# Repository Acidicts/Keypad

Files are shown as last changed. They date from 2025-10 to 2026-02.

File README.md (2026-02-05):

# A Numpad or Keypad
## Do as you please with it

It has:
- 16 standard 1:1 aspect ratio keys
- A 1:2 aspect ratio key
- Rotary Encoder
- Seeed Studio Xiao RP2040

The order of assembly/soldering is:
- The Diodes
- The Seeed Studio Xiao RP2040
- The Rotary Encoder
- Keys
- Keycaps Encoder Knob

This is yet to have firmware made for it as it is easier to debug with the actual hardware on hand.
Will be using either **KMK** or **QMK** most likely (kmk due to being easier to learn) and will be referencing [this](https://github.com/Acidicts/Hackpad)

The Rotary Encoder can be used as an audio knob all the way to being a selector for presets for different key setups.

Here is a render of the finished product:
keypad_render

Case:


<div>
  
  
</div>

https://github.com/user-attachments/assets/b589e256-21bc-4e0a-8186-24f3bf2696fe



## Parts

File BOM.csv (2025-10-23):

Item | Store | Quantity | Price(£) | Price ($) | Shipping | Total
Seeed Studio Xiao RP2040 | Seeed Studio | 1 | N/A | $3.90 | $3.68 | $7.58
Key Switches (10 pack) | Amazon | 2 | £3.49 | $9.28 | Prime | $9.28
PCB | JLCPCB | 5 | N/A | $2.00 | $2.20 | $4.20
Diodes ( Multiples of 50 ) | LCSC | 1 | N/A | $0.52 | $4.35 | $4.89
EC11 Rotary Encoder | LCSC | 1 | N/A | $1.81 | $4.35 | $7.57
 |  |  |  |  |  | $33.52

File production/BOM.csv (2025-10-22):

Comment | Designator | Footprint | JLCPCB Part #?optional?
BAV16W | D1,D2,D3,D4,D5,D6,D7,D8,D9,D10,D12,D13,D14,D15,D16,D17,D18,D19,D20 | SOD123

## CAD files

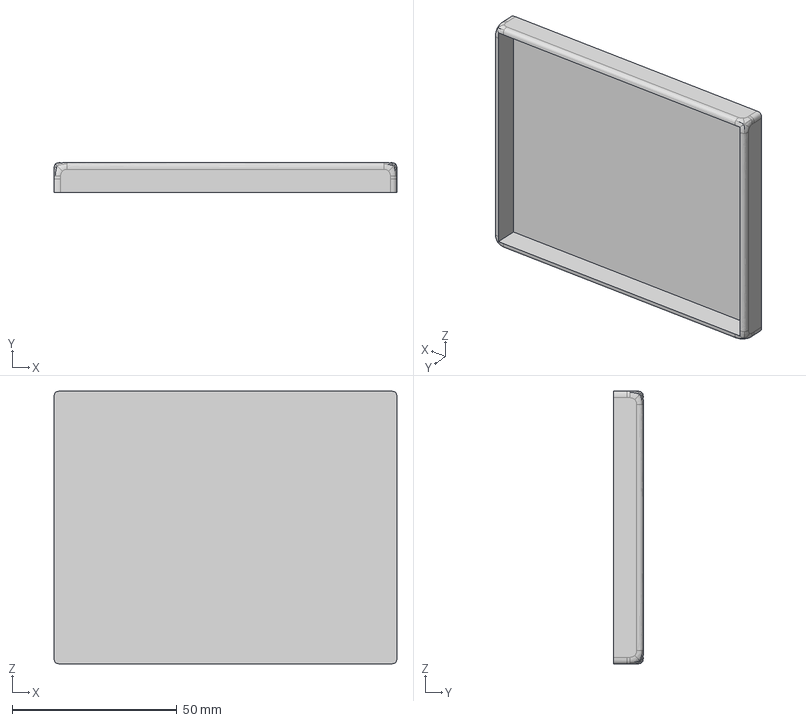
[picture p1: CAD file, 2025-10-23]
case/keypad.step
104.0 x 9.00 x 82.7 mm

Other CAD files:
case/bottom.3mf

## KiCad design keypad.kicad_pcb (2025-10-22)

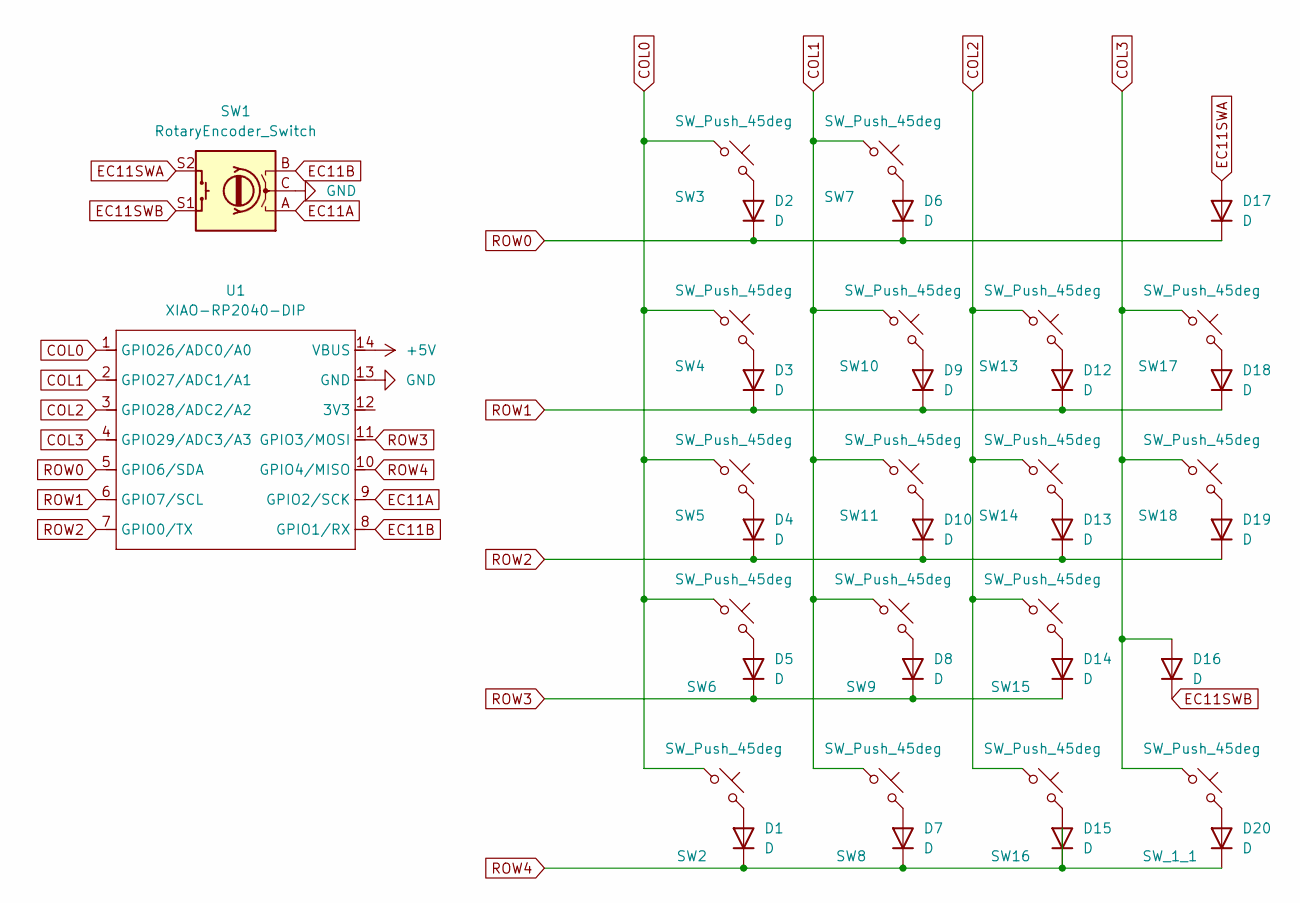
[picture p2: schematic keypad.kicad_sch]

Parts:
D1, D2, D3, D4, D5, D6, D7, D8, D9, D10, D12, D13, D14, D15, D16, D17, D18, D19, D20: D; D_SOD-123
SW1: RotaryEncoder_Switch; RotaryEncoder_Alps_EC11E-Switch_Vertical_H20mm
SW2, SW3, SW4, SW5, SW6, SW7, SW8, SW9, SW10, SW11, SW13, SW14, SW15, SW16, SW17, SW18: SW_Push_45deg; SW_Cherry_MX_1.00u_PCB
SW_1_1: SW_Push_45deg; SW_Cherry_MX_1.00u_PCB
U1: XIAO-RP2040-DIP

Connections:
+5V: U1.14 (VBUS)
COL0: SW2.1, SW3.1, SW4.1, SW5.1, SW6.1, U1.1 (GPIO26/ADC0/A0)
COL1: SW7.1, SW8.1, SW9.1, SW10.1, SW11.1, U1.2 (GPIO27/ADC1/A1)
COL2: SW13.1, SW14.1, SW15.1, SW16.1, U1.3 (GPIO28/ADC2/A2)
COL3: D16.2 (A), SW17.1, SW18.1, SW_1_1.1, U1.4 (GPIO29/ADC3/A3)
EC11A: SW1.A, U1.9 (GPIO2/SCK)
EC11B: SW1.B, U1.8 (GPIO1/RX)
EC11SWA: D17.2 (A), SW1.S2
EC11SWB: D16.1 (K), SW1.S1
GND: SW1.C, SW1.MP, U1.13 (GND)
unnamed: D1.2 (A), SW2.2
unnamed: D2.2 (A), SW3.2
unnamed: D3.2 (A), SW4.2
unnamed: D4.2 (A), SW5.2
unnamed: D5.2 (A), SW6.2
unnamed: D6.2 (A), SW7.2
unnamed: D7.2 (A), SW8.2
unnamed: D8.2 (A), SW9.2
unnamed: D9.2 (A), SW10.2
unnamed: D10.2 (A), SW11.2
unnamed: D12.2 (A), SW13.2
unnamed: D13.2 (A), SW14.2
unnamed: D14.2 (A), SW15.2
unnamed: D15.2 (A), SW16.2
unnamed: D18.2 (A), SW17.2
unnamed: D19.2 (A), SW18.2
unnamed: D20.2 (A), SW_1_1.2
ROW0: D2.1 (K), D6.1 (K), D17.1 (K), U1.5 (GPIO6/SDA)
ROW1: D3.1 (K), D9.1 (K), D12.1 (K), D18.1 (K), U1.6 (GPIO7/SCL)
ROW2: D4.1 (K), D10.1 (K), D13.1 (K), D19.1 (K), U1.7 (GPIO0/TX)
ROW3: D5.1 (K), D8.1 (K), D14.1 (K), U1.11 (GPIO3/MOSI)
ROW4: D1.1 (K), D7.1 (K), D15.1 (K), D20.1 (K), U1.10 (GPIO4/MISO)

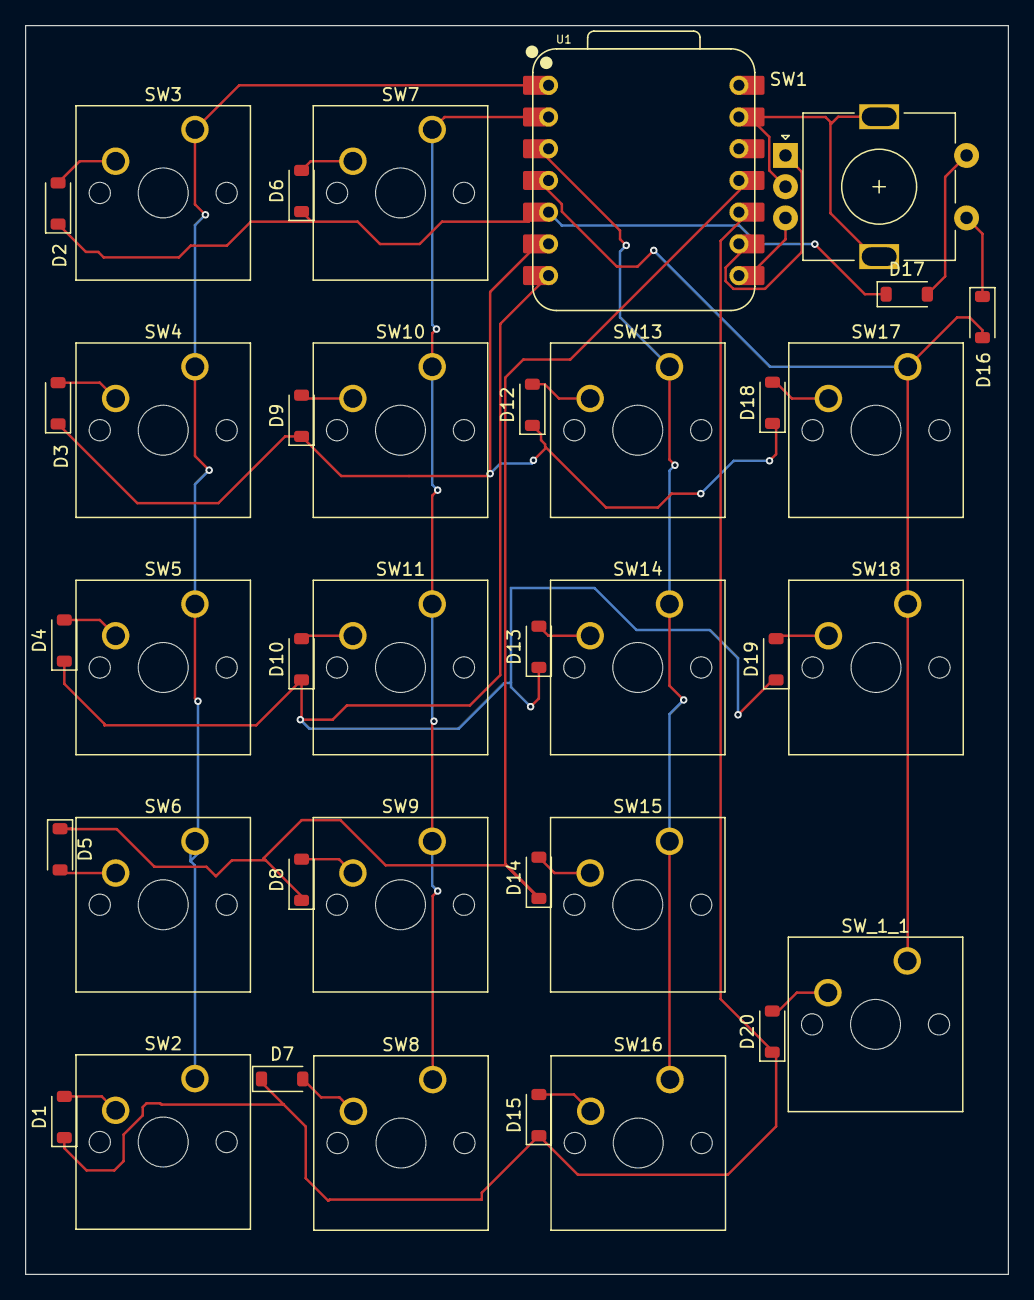
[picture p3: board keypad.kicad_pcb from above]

Board: 2 copper layers, 78.7 x 100.0 mm, 38 parts (0 on the bottom side), 31 nets.

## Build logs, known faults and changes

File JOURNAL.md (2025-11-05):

<!--
  ===================    !!READ THIS NOTICE!!   ====================
  DO NOT edit this file manually. Your changes WILL BE OVERWRITTEN!
  This journal is auto generated and updated by Hack Club Blueprint.
  To edit this file, please edit your journal entries on Blueprint.
  ==================================================================
-->

## 10/20/2025 - Created the Schematic for the Keypad - 0.7hrs  

Made the schematic key arrangement is 4 columns by 5 rows:
- K = Key 
- E = Rotary Encoder
- 2K = 2 tall key 1x2 size top and bottom will be written out

K K K E
K K K K
K K K K
K K K 2K
K K K 2K



## 10/21/2025 10:46 PM - Routed PCB - 1.4hrs  

I routed the pcb and removed a key to make space for the Xiao Seed Studio on the board. So the board has 4 columns with 5 rows with a total of 17 Keys and an rotary encoder



## 10/21/2025 10:49 PM - Made a Board Render - 0.1hrs  

I added a margin and made a render of the pcb to get an idea of what the shape of it will be and to start thinking if I want a case or enjoy the pcb in all its glory. 


## 10/21/2025 11 PM - Complied with DRC rules - 1hrs  

I selected ignore all for the clearance drc rules as it was due to using a smaller diode size which brought two wires / tracks too close to each other causing the errors.



## 10/22/2025 11:09 PM - PCB Case - 2hrs  

Made Case for the keypad and tried getting the pcb into jlcpcb but failed, due to kicad exporting BOM and CPL wrong, and I couldn't find a diode for the 203_603metric footprint



## 10/22/2025 11:47 PM - Looking for parts - 1hrs  

PCb and diodes have been found but currently looking for keyswitches and keys to put on the board and yet to look for the seeed studio xiao rp2040 microcontroller




## 10/23/2025 5:03 PM - Found Keys and MCU - 1 hrs  

I found the remaining components I need to buy: which are the seeed studio xiao rp2040, rotary encoder and key switches. The Case and keycaps will be 3D printed.





x2 of these


## 10/23/2025 5:33 PM - Organised a BOM for total price for all items - 0.4hrs  

I organised the items to show the usd prices for anything is gbp instead and organise the raw item prices vs shipping costs. This helps understand the costs for reviewers



## 10/23/2025 5:44 PM - Forgot to add this - 0.1hrs  

Filament spool in black to give the Case and Keycaps a matte black colour as I don't have a matte filament that could be substituted in. Found on amazon for lower than my normal filament price.

~ Note Filament was removed from BOM



## 10/23/2025 8 PM - Found cheaper products - 0.7hrs  

I found cheaper products from different retailers, to lower the price. Removed filament from BOM.
Using 4 retailers based on price, seeed studio for the rp2040 board, jlcpcb for the pcb, lcsc for the diodes and rotary encoder, Amazon for the mx switches.



## 10/24/2025 - Ordered Seeed Studio Xiao RP2040 - 0.5hrs  

Put in my order for:
- seeed studio xiao rp2040 - Bit pricey but used discount code so now only paying shipping
- pcb - The pcb the fun part
- lcsc parts - x50 BAV16W diodes and a rotary encoder

Addresses and order codes censored







## 11/5/2025 - Soldered PCB and added keycaps  

All deliveries arrived and I soldered the diodes first then the microcontroller then the rotary encoder and finally the switches before adding keycaps etc.

WhatsApp Image 2025-11-05 at 18.08.31_fab62910

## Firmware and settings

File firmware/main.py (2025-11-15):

import supervisor

# Check if SW1 was pressed at boot - if so, don't run keyboard code
try:
    if supervisor.runtime.serial_bytes_available:
        print("SW1 was pressed at boot - keyboard disabled for file editing")
        while True:
            pass  # Infinite loop, do nothing
except:
    pass

import board
from kmk.kmk_keyboard import KMKKeyboard
from kmk.keys import KC, Key
from kmk.scanners import DiodeOrientation
from kmk.extensions.media_keys import MediaKeys
from kmk.modules.layers import Layers
import digitalio

# Keyboard configuration
keyboard = KMKKeyboard()

# Pin configuration for columns and rows
keyboard.col_pins = (board.D0, board.D1, board.D2, board.D3)
keyboard.row_pins = (board.D4, board.D5, board.D6, board.D10, board.D9)

# Diode orientation: COL2ROW means diodes point from columns to rows
keyboard.diode_orientation = DiodeOrientation.COL2ROW

# Add layers module for multiple modes
layers = Layers()
keyboard.modules.append(layers)

# Initialize RGB NeoPixel on pin 14
pixels = None
try:
    import neopixel
    # NeoPixel is on pin 14 (not board.NEOPIXEL)
    try:
        led_pin = board.D14
    except:
        # Fallback to NEOPIXEL if D14 doesn't exist
        led_pin = board.NEOPIXEL
    
    pixels = neopixel.NeoPixel(led_pin, 1, brightness=0.3, auto_write=True)
    pixels.fill((0, 0, 0))  # Start with LED off
    print(f"NeoPixel initialized on pin 14")
except Exception as e:
    print(f"NeoPixel not available: {e}")
    pixels = None

# Media keys support
keyboard.extensions.append(MediaKeys())

# Mode colors (R, G, B) values 0-255
MODE_COLORS = [
    (255, 0, 0),    # Mode 0 (Layer 0): Red - Numpad
    (0, 255, 0),    # Mode 1 (Layer 1): Green - Media Controls
    (0, 0, 255),    # Mode 2 (Layer 2): Blue - Macros/Shortcuts
]

# Manual rotary encoder implementation - only trigger on full detent
class ManualEncoder:
    def __init__(self, pin_a, pin_b):
        self.pin_a = digitalio.DigitalInOut(pin_a)
        self.pin_a.direction = digitalio.Direction.INPUT
        self.pin_a.pull = digitalio.Pull.UP
        
        self.pin_b = digitalio.DigitalInOut(pin_b)
        self.pin_b.direction = digitalio.Direction.INPUT
        self.pin_b.pull = digitalio.Pull.UP
        
        # Track state for full rotation detection
        self.last_a = self.pin_a.value
        self.position = 0
        
        print(f"Manual encoder initialized")
    
    def update(self):
        """Check encoder - only returns direction on A pin falling edge when both pins match"""
        a = self.pin_a.value
        b = self.pin_b.value
        
        # Only detect on falling edge of pin A
        if self.last_a and not a:
            self.last_a = a
            # Check pin B to determine direction
            if b:
                return -1  # Counter-clockwise
            else:
                return 1   # Clockwise
        
        self.last_a = a
        return 0

# Create manual encoder instance
manual_encoder = ManualEncoder(board.D8, board.D7)

# Current mode tracking
class ModeManager:
    def __init__(self):
        self.current_mode = 0
        self.mode_select_active = False
        self.initialized = False
        self.counter = 0
        self.blink_counter = 0
        self.blink_state = False
        self.pending_key_release = None
        self.release_counter = 0
    
    def set_mode_color(self):
        """Update LED color based on current mode"""
        if pixels:
            try:
                color = MODE_COLORS[self.current_mode % len(MODE_COLORS)]
                pixels.fill(color)
                pixels.show()
                print(f"LED set to mode {self.current_mode}: {color}")
            except Exception as e:
                print(f"LED error: {e}")
    
    def update_blink(self):
        """Handle LED blinking in mode select"""
        if self.mode_select_active and pixels:
            self.blink_counter += 1
            if self.blink_counter >= 30:  # Blink every ~30 scans (about 0.3s)
                self.blink_counter = 0
                self.blink_state = not self.blink_state
                try:
                    if self.blink_state:
                        pixels.fill(MODE_COLORS[self.current_mode])
                    else:
                        pixels.fill((0, 0, 0))
                    pixels.show()
                except:
                    pass
    
    def cycle_mode(self, direction):
        """Cycle through modes when encoder is rotated during mode selection"""
        if self.mode_select_active:
            if direction > 0:  # Clockwise
                self.current_mode = (self.current_mode + 1) % 3
            else:  # Counter-clockwise
                self.current_mode = (self.current_mode - 1) % 3
            print(f"Mode changed to: {self.current_mode}")
            self.set_mode_color()
            keyboard.active_layers = [self.current_mode]
            return True
        return False
    
    def toggle_mode_select(self):
        """Toggle mode selection on/off"""
        self.mode_select_active = not self.mode_select_active
        self.blink_counter = 0
        self.blink_state = False
        print(f"Mode select: {self.mode_select_active}")
        if not self.mode_select_active:
            # Exiting mode select - set solid color
            self.set_mode_color()
    
    def check_init(self):
        """Check if we should initialize the color"""
        if not self.initialized:
            self.counter += 1
            if self.counter > 10:  # Wait for a few scan cycles
                self.set_mode_color()
                self.initialized = True
    
    def handle_key_release(self):
        """Handle auto-release of encoder keys"""
        if self.pending_key_release:
            self.release_counter += 1
            if self.release_counter >= 2:  # Release after 2 scans
                keyboard.remove_key(self.pending_key_release)
                self.pending_key_release = None
                self.release_counter = 0

mode_manager = ModeManager()

# Create a custom key class for mode selection
class ModeSelectKey(Key):
    def __init__(self):
        super().__init__()
    
    def on_press(self, keyboard, coord_int=None, coord_raw=None):
        mode_manager.toggle_mode_select()
        return False
    
    def on_release(self, keyboard, coord_int=None, coord_raw=None):
        return False

KC.MODE_SELECT = ModeSelectKey()

# Keymap - 3 layers (modes)
keyboard.keymap = [
    # LAYER 0: NUMPAD MODE (RED)
    [
        KC.N7,         KC.N8,         KC.NO,         KC.MODE_SELECT,     # Row 0
        KC.N4,         KC.N5,         KC.N6,         KC.PLUS,            # Row 1
        KC.N1,         KC.N2,         KC.N3,         KC.MINS,            # Row 2
        KC.N0,         KC.DOT,        KC.ENT,        KC.NO,              # Row 3
        KC.BSPC,       KC.PAST,       KC.PSLS,       KC.EQL,             # Row 4
    ],
    
    # LAYER 1: MEDIA CONTROL MODE (GREEN)
    [
        KC.MPRV,       KC.MPLY,       KC.NO,         KC.MODE_SELECT,     # Row 0
        KC.NO,         KC.NO,         KC.NO,         KC.MNXT,            # Row 1
        KC.NO,         KC.NO,         KC.NO,         KC.MUTE,            # Row 2
        KC.NO,         KC.NO,         KC.NO,         KC.NO,              # Row 3
        KC.NO,         KC.NO,         KC.NO,         KC.NO,              # Row 4
    ],
    
    # LAYER 2: MACRO/SHORTCUT MODE (BLUE)
    [
        KC.F13,        KC.F14,        KC.NO,         KC.MODE_SELECT,     # Row 0
        KC.F15,        KC.F16,        KC.F17,        KC.F18,             # Row 1
        KC.F19,        KC.F20,        KC.F21,        KC.F22,             # Row 2
        KC.LCTL(KC.C), KC.LCTL(KC.V), KC.LCTL(KC.Z), KC.NO,              # Row 3
        KC.LCTL(KC.S), KC.LCTL(KC.A), KC.LCTL(KC.X), KC.LCTL(KC.Y),     # Row 4
    ],
]

# Hook into before_matrix_scan to handle encoder, LED blinking and initialization
def custom_before_matrix_scan():
    mode_manager.check_init()
    mode_manager.update_blink()
    mode_manager.handle_key_release()
    
    # Check encoder
    direction = manual_encoder.update()
    if direction != 0:
        if mode_manager.mode_select_active:
            # In mode select - cycle modes
            mode_manager.cycle_mode(direction)
        else:
            # Normal mode - send volume keys with auto-release
            # First release any pending key
            if mode_manager.pending_key_release:
                keyboard.remove_key(mode_manager.pending_key_release)
            
            # Add the new key
            if direction < 0:
                keyboard.add_key(KC.VOLU)
                mode_manager.pending_key_release = KC.VOLU
            else:
                keyboard.add_key(KC.VOLD)
                mode_manager.pending_key_release = KC.VOLD
            
            mode_manager.release_counter = 0

keyboard.before_matrix_scan = custom_before_matrix_scan

print("Manual encoder ready!")

if __name__ == '__main__':

    keyboard.go()

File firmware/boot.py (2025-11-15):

import usb_hid
import board
import digitalio
import storage
import supervisor
import time

# Enable USB HID devices
usb_hid.enable(
    (usb_hid.Device.KEYBOARD,
     usb_hid.Device.CONSUMER_CONTROL)
)

# SW1 is at position (Col 3, Row 0)
# Col 3 = D3, Row 0 = D4
# Diodes are Col to Row (COL2ROW)
col3_pin = board.D3
row0_pin = board.D4

# Set up row pin as output (drive it LOW)
row0 = digitalio.DigitalInOut(row0_pin)
row0.direction = digitalio.Direction.OUTPUT
row0.value = False  # Drive row LOW

# Set up column pin as input with pullup
col3 = digitalio.DigitalInOut(col3_pin)
col3.direction = digitalio.Direction.INPUT
col3.pull = digitalio.Pull.UP

# Small delay to let pins stabilize
time.sleep(0.01)

# Read the column
# If SW1 is pressed, col3 will be pulled LOW through the diode
# If SW1 is NOT pressed, col3 will stay HIGH (pulled up)
button_pressed = not col3.value

# Clean up
col3.deinit()
row0.deinit()

if button_pressed:
    # Button pressed - enable USB drive and prevent code from running
    print("SW1 pressed at boot - USB drive enabled, main.py disabled")
    supervisor.disable_autoreload()
    # Don't disable USB drive so we can edit files
else:
    # Button not pressed - disable USB drive and run normally
    storage.disable_usb_drive()
    print("USB drive disabled - running normally")

# Store button state in supervisor runtime for main.py to check
supervisor.runtime.serial_bytes_available = button_pressed

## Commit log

2025-10-23 Fix prices and formatting in BOM.csv
    Updated the BOM.csv file to correct the price of Diodes and adjust the formatting.
    [BOM.csv]
2025-10-23 Fix total price in BOM.csv
    Updated total price in BOM.csv.
    [BOM.csv]
2025-10-23 Fix total cost in BOM.csv
    Updated total cost due to changes in item prices.
    [BOM.csv]
